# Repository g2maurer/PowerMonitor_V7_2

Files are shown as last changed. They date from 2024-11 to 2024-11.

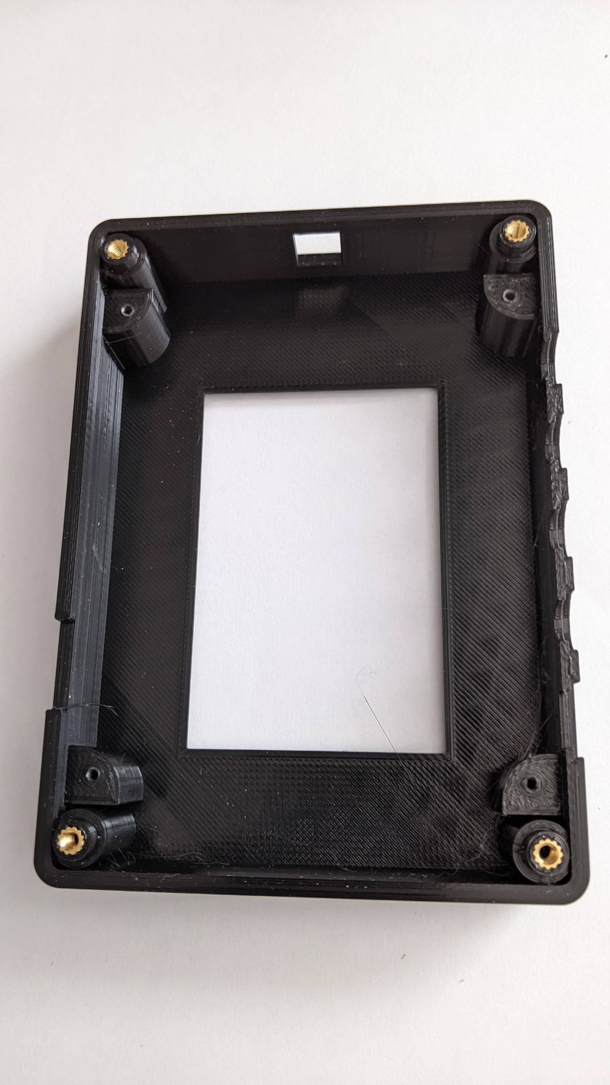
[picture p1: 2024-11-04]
Images/Enclosure_top.jpg

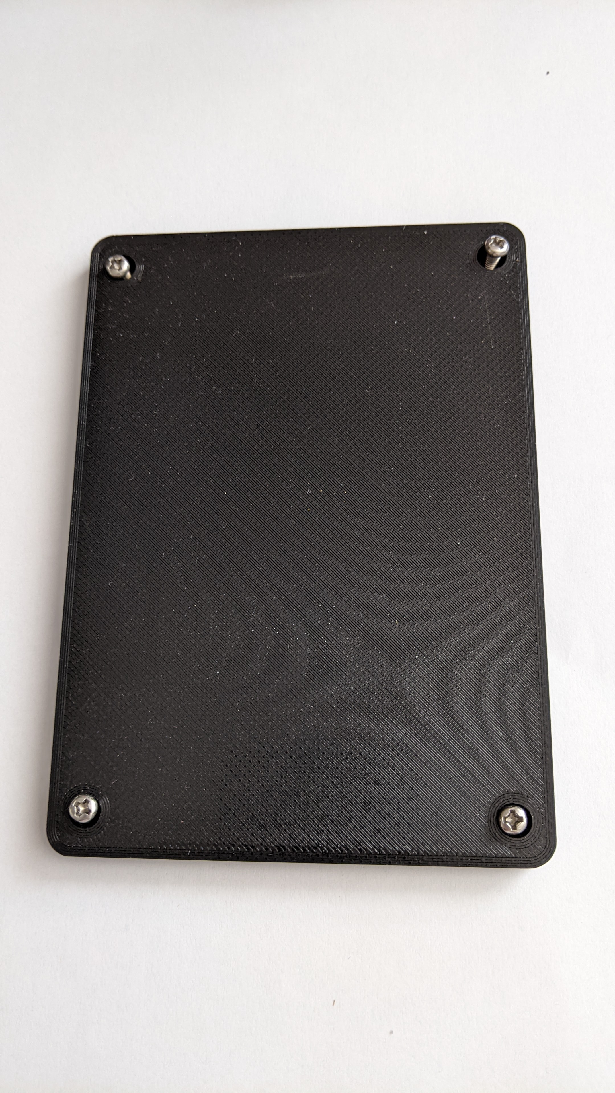
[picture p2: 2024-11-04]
Images/Enclosure back.jpg

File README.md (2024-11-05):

# PowerMonitor_V7_2

## Code:
* ESP32 code files.
* Compile with Arduino Sketch IDE version 1.8.19.
* ESP Board Manager - esp32 by Espressif Systems version 2.0.17.
	* NOTE: Don't try to use newer versions (3.0.x or newer).
* Board: DOIT ESP32 DEVKIT V1

* Required Libraries:
	* RV3028C7.h - Realtime Clock
	* TimeLib.h -
	* Adafruit_ADS1X15.h - Analog-to-Digital converter.
	* WiFi.h
	* WiFiUdp.h
	* NTPClient.h
	* TFT_eSPI.h - TFT screen with Touch.
	* SD.h - SD memory card.
	* SPIFFS.h

## Enclosure:
* STL files for enclosure (front and back).
* FreeCAD enclosure design files.

## Images:
* Image files for PCB and enclosure.

## PCB:
* KiCAD
	* PCB design files.
* PCB Components:
	* ESP32-WROOM-32S.
	* 3.5 inch TFT with Touch. 
		* SPI interface.
	* ADS1015 Analog to Digital converter ICs. 
		* Configured in differntail mode, two CT channels per A2D converter IC.
	* CH340K USB to serial inteface IC.
		* microUSB interface (USB-B).
	* RV3028__C7 Realtime Clock IC and battery. 
		* Not required if WiFi connected to get the time via NTP.

## Misc:
* TFT user setup file. 
	* Contains the ESP32 to TFT pin definitions.
	* The TFT_eSPI "User_Setup_Select.h" file selects the User_Setup file. 
	* Use ILI9488_g2m.h file found in Misc directory for User_Setup file.

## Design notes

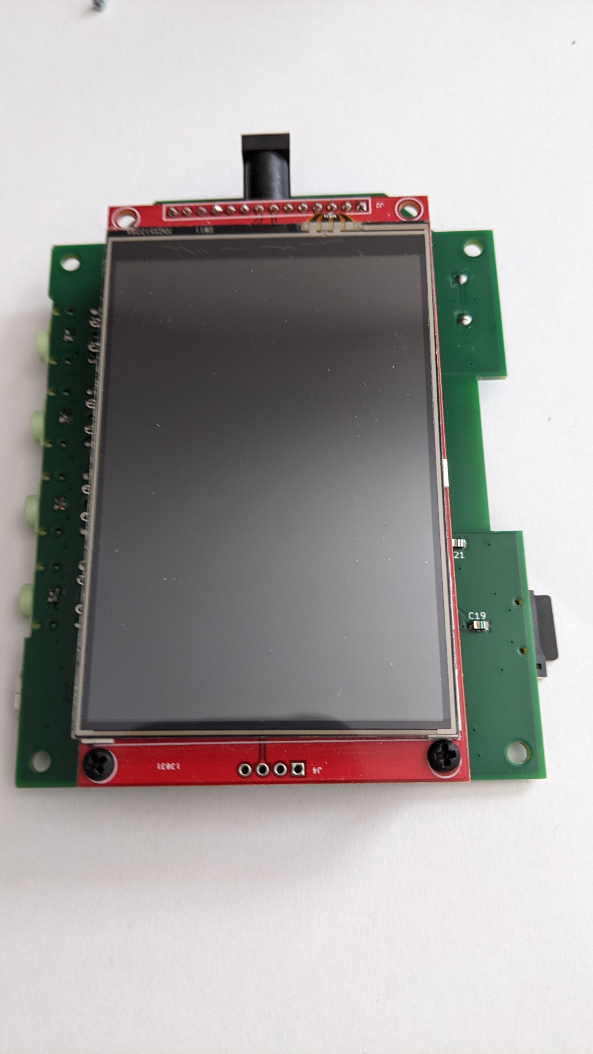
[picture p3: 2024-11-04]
Images/PCB_back_w_TFT.jpg

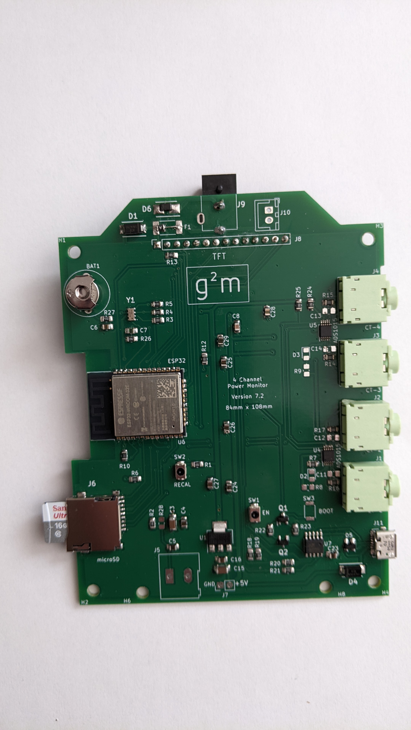
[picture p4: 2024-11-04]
Images/PCB_front.jpg

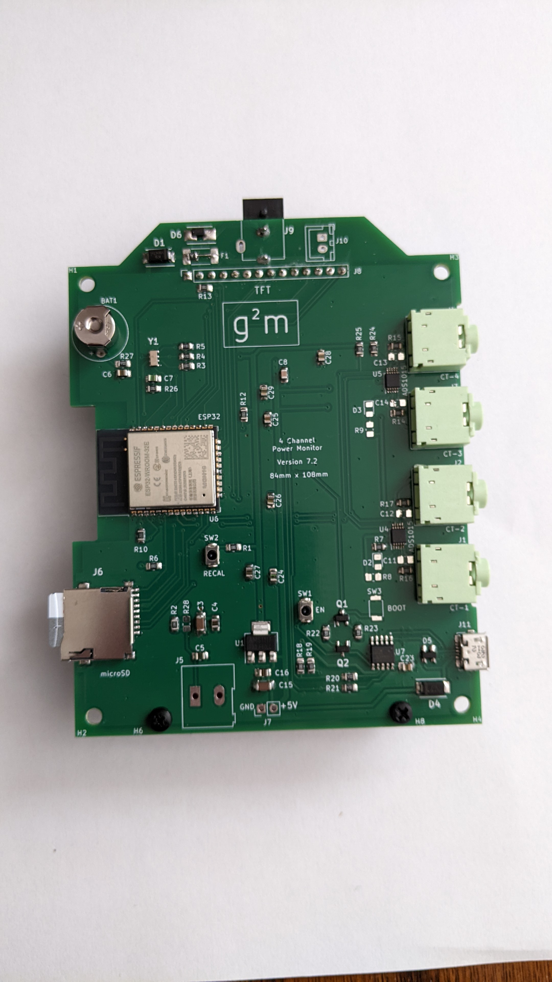
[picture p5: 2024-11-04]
Images/PCB_front_w_TFT.jpg

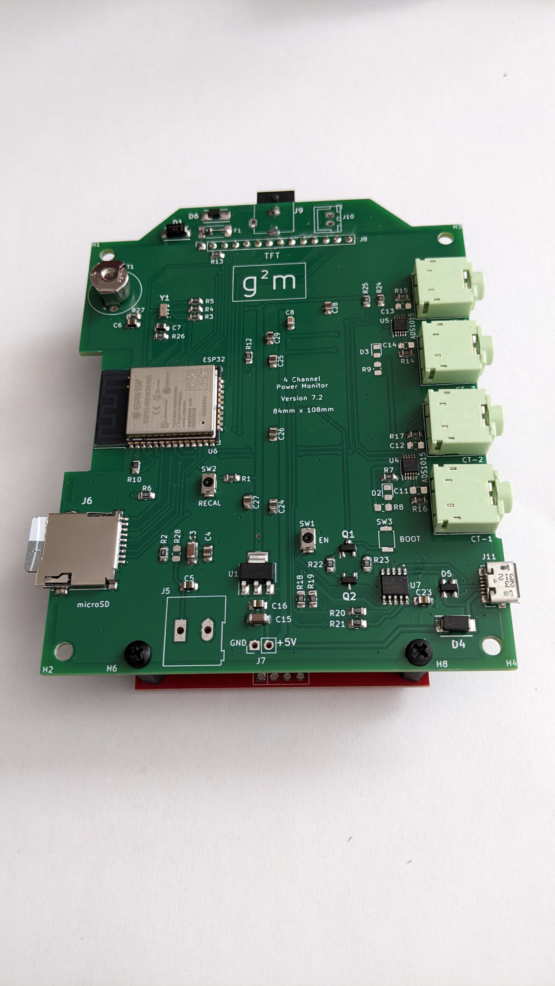
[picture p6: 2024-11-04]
Images/PCB_front_w_TFT_2.jpg

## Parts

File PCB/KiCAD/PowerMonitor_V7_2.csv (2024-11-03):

Source: | C:\Users\gmaur\Documents\KiCad Projects\PowerMonitor_V7_2\PowerMonitor_V7_2.sch
Date: | 8/19/2024 11:29:42 AM
Tool: | Eeschema (5.1.10)-1
Generator: | C:\Program Files\KiCad\bin\scripting\plugins/bom_csv_grouped_by_value.py
Component Count: | 94
Individual Components:
Item | Qty | Reference(s) | Value | LibPart | Footprint | Datasheet | Arrow Part Number | Arrow Price/Stock | Description | Height | Manufacturer_Name | Manufacturer_Part_Number | Mouser Part Number | Mouser Price/Stock
 |  | BAT1 | SR754 | Custom:SR754_Battery | BatteruyHolder:Battery_Retainer_size_13 | ~
 |  | C1 | 100nF | Device:C_Small | Capacitor_SMD:C_0805_2012Metric_Pad1.18x1.45mm_HandSolder | ~
 |  | C2 | 100nF | Device:C_Small | Capacitor_SMD:C_0805_2012Metric_Pad1.18x1.45mm_HandSolder | ~
 |  | C3 | 10uF | Device:CP_Small | Capacitor_SMD:C_1206_3216Metric_Pad1.33x1.80mm_HandSolder | ~
 |  | C4 | 100nF | Device:C_Small | Capacitor_SMD:C_0805_2012Metric_Pad1.18x1.45mm_HandSolder | ~
 |  | C5 | 100nF | Device:C_Small | Capacitor_SMD:C_0805_2012Metric_Pad1.18x1.45mm_HandSolder | ~
 |  | C6 | 100nF | Device:C_Small | Capacitor_SMD:C_0805_2012Metric_Pad1.18x1.45mm_HandSolder | ~
 |  | C7 | 100nF | Device:C_Small | Capacitor_SMD:C_0805_2012Metric_Pad1.18x1.45mm_HandSolder | ~
 |  | C8 | 1uF | Device:C_Small | Capacitor_SMD:C_0805_2012Metric_Pad1.18x1.45mm_HandSolder | ~
 |  | C9 | 10nF | Device:C_Small | Capacitor_SMD:C_0805_2012Metric_Pad1.18x1.45mm_HandSolder | ~
 |  | C10 | 2.2uF | Device:CP_Small | Capacitor_SMD:C_1206_3216Metric_Pad1.33x1.80mm_HandSolder | ~
 |  | C11 | 10nF | Device:C_Small | Capacitor_SMD:C_0805_2012Metric_Pad1.18x1.45mm_HandSolder | ~
 |  | C12 | 10nF | Device:C_Small | Capacitor_SMD:C_0805_2012Metric_Pad1.18x1.45mm_HandSolder | ~
 |  | C13 | 10nF | Device:C_Small | Capacitor_SMD:C_0805_2012Metric_Pad1.18x1.45mm_HandSolder | ~
 |  | C14 | 10nF | Device:C_Small | Capacitor_SMD:C_0805_2012Metric_Pad1.18x1.45mm_HandSolder | ~
 |  | C15 | 10uF | Device:C_Small | Capacitor_SMD:C_1206_3216Metric_Pad1.33x1.80mm_HandSolder | ~
 |  | C16 | 100nF | Device:C_Small | Capacitor_SMD:C_0805_2012Metric_Pad1.18x1.45mm_HandSolder | ~
 |  | C17 | 100nF | Device:C_Small | Capacitor_SMD:C_0805_2012Metric_Pad1.18x1.45mm_HandSolder | ~
 |  | C18 | 10uF | Device:C_Small | Capacitor_SMD:C_1206_3216Metric_Pad1.33x1.80mm_HandSolder | ~
 |  | C19 | 100nF | Device:C_Small | Capacitor_SMD:C_0805_2012Metric_Pad1.18x1.45mm_HandSolder | ~
 |  | C20 | 10nF | Device:C_Small | Capacitor_SMD:C_0805_2012Metric_Pad1.18x1.45mm_HandSolder | ~
 |  | C21 | 100nF | Device:C_Small | Capacitor_SMD:C_0805_2012Metric_Pad1.18x1.45mm_HandSolder | ~
 |  | C22 | 100nF | Device:C_Small | Capacitor_SMD:C_0805_2012Metric_Pad1.18x1.45mm_HandSolder | ~
 |  | C23 | 100nF | Device:C_Small | Capacitor_SMD:C_0805_2012Metric_Pad1.18x1.45mm_HandSolder | ~
 |  | C24 | 100nF | Device:C_Small | Capacitor_SMD:C_0805_2012Metric_Pad1.18x1.45mm_HandSolder | ~
 |  | C25 | 100nF | Device:C_Small | Capacitor_SMD:C_0805_2012Metric_Pad1.18x1.45mm_HandSolder | ~
 |  | C26 | 100nF | Device:C_Small | Capacitor_SMD:C_0805_2012Metric_Pad1.18x1.45mm_HandSolder | ~
 |  | C27 | 100nF | Device:C_Small | Capacitor_SMD:C_0805_2012Metric_Pad1.18x1.45mm_HandSolder | ~
 |  | C28 | 100nF | Device:C_Small | Capacitor_SMD:C_0805_2012Metric_Pad1.18x1.45mm_HandSolder | ~
 |  | C29 | 100nF | Device:C_Small | Capacitor_SMD:C_0805_2012Metric_Pad1.18x1.45mm_HandSolder | ~
 |  | D1 | 1N5819 | Diode:1N5819 | SamacSys_Parts:DIOM5436X295N | http://www.vishay.com/docs/88525/1n5817.pdf
 |  | D2 | LED | Device:LED | LED_SMD:LED_0805_2012Metric_Pad1.15x1.40mm_HandSolder | ~
 |  | D3 | LED | Device:LED | LED_SMD:LED_0805_2012Metric_Pad1.15x1.40mm_HandSolder | ~
 |  | D4 | 5819SMJE3_TR13 | SamacSys:5819SMJE3_TR13 | SamacSys_Parts:DIOM5436X295N | https://www.arrow.com/en/products/5819smje3tr13/microchip-technology | 5819SMJE3/TR13 | null?region=nac | Schottky Diodes & Rectifiers Schottky | 2.95 | Microchip | 5819SMJE3/TR13 | 494-5819SMJE3/TR13 | https://www.mouser.co.uk/ProductDetail/Microchip-Technology/5819SMJE3-TR13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
 |  | D5 | SP0503BAHT | Power_Protection:SP0503BAHT | Package_TO_SOT_SMD:SOT-143 | http://www.littelfuse.com/~/media/files/littelfuse/technical%20resources/documents/data%20sheets/sp05xxba.pdf
 |  | D6 | SMAZ6V2 | Device:D_Zener | DIODE_SMD:DO-214AA | ~
 |  | F1 | Polyfuse_Small | Device:Polyfuse_Small | Fuse:Fuse_2512_6332Metric_Pad1.52x3.35mm_HandSolder | ~
 |  | H1 | MountingHole | Mechanical:MountingHole | MountingHole:MountingHole_3.2mm_M3 | ~
 |  | H2 | MountingHole | Mechanical:MountingHole | MountingHole:MountingHole_3.2mm_M3 | ~
 |  | H3 | MountingHole | Mechanical:MountingHole | MountingHole:MountingHole_3.2mm_M3 | ~
 |  | H4 | MountingHole | Mechanical:MountingHole | MountingHole:MountingHole_3.2mm_M3 | ~
 |  | H6 | TFTHole | Mechanical:MountingHole | MountingHole:MountingHole_3.2mm_M3 | ~
 |  | H8 | TFTHole | Mechanical:MountingHole | MountingHole:MountingHole_3.2mm_M3 | ~
 |  | J1 | CT-1 | PowerMonitor_V4-rescue:PJ307_AudioJack_3.5mm-Custom-PowerMonitor_V3-rescue | Connector_Custom:Jack_3.5mm_PJ307_Horizontal | ~
 |  | J2 | CT-2 | PowerMonitor_V4-rescue:PJ307_AudioJack_3.5mm-Custom-PowerMonitor_V3-rescue | Connector_Custom:Jack_3.5mm_PJ307_Horizontal | ~
 |  | J3 | CT-3 | PowerMonitor_V4-rescue:PJ307_AudioJack_3.5mm-Custom-PowerMonitor_V3-rescue | Connector_Custom:Jack_3.5mm_PJ307_Horizontal | ~
 |  | J4 | CT-4 | PowerMonitor_V4-rescue:PJ307_AudioJack_3.5mm-Custom-PowerMonitor_V3-rescue | Connector_Custom:Jack_3.5mm_PJ307_Horizontal | ~
 |  | J5 | Thermister | Connector:Screw_Terminal_01x02 | TerminalBlock:TerminalBlock_Altech_AK300-2_P5.00mm | ~
 |  | J6 | MSD-4-A | SamacSys:MSD-4-A | SamacSys_Parts:MSD4A | https://www.cuidevices.com/product/resource/pdf/msd-4-a.pdf |  |  | Memory Card Connectors 9 Positions, Push In, Auto Eject Out, SMT, 1.8 mm Height Above Board, | 2 | CUI Devices | MSD-4-A | 179-MSD-4-A | https://www.mouser.co.uk/ProductDetail/CUI-Devices/MSD-4-A?qs=Z%252BL2brAPG1Jll%252BQTi%252Btupg%3D%3D
 |  | J7 | Test_5V | Connector_Generic:Conn_01x02 | Connector_PinHeader_2.54mm:PinHeader_1x02_P2.54mm_Vertical | ~
 |  | J8 | TFT | Connector_Generic:Conn_01x14 | Connector_PinSocket_2.54mm:PinSocket_1x14_P2.54mm_Vertical | ~
 |  | J9 | Barrel_Jack_Switch | Connector:Barrel_Jack_Switch | Connector_Custom:PJ-059A | ~
 |  | J10 | +5V IN | Connector_Generic:Conn_01x02 | Connector_JST:JST_XH_B2B-XH-A_1x02_P2.50mm_Vertical | ~
 |  | J11 | USB_B_Micro | Connector:USB_B_Micro | Connector_USB:USB_Micro-B_Molex_47346-0001 | ~
 |  | Q1 | MMSS8050-H-TP | SamacSys:MMSS8050-H-TP | SamacSys_Parts:SOT95P237X125-3N | https://www.mccsemi.com/pdf/Products/MMSS8050(SOT-23).pdf | MMSS8050-H-TP | https://www.arrow.com/en/products/mmss8050-h-tp/micro-commercial-components?region=europe | Small Signal Bipolar Transistors | 1.25 | MCC | MMSS8050-H-TP | 833-MMSS8050-H-TP | https://www.mouser.co.uk/ProductDetail/Micro-Commercial-Components-MCC/MMSS8050-H-TP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
 |  | Q2 | MMSS8050-H-TP | SamacSys:MMSS8050-H-TP | SamacSys_Parts:SOT95P237X125-3N | https://www.mccsemi.com/pdf/Products/MMSS8050(SOT-23).pdf | MMSS8050-H-TP | https://www.arrow.com/en/products/mmss8050-h-tp/micro-commercial-components?region=europe | Small Signal Bipolar Transistors | 1.25 | MCC | MMSS8050-H-TP | 833-MMSS8050-H-TP | https://www.mouser.co.uk/ProductDetail/Micro-Commercial-Components-MCC/MMSS8050-H-TP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
 |  | R1 | 10k | Device:R_Small_US | Resistor_SMD:R_0805_2012Metric_Pad1.20x1.40mm_HandSolder | ~
 |  | R2 | 1k | Device:R_Small_US | Resistor_SMD:R_0805_2012Metric_Pad1.20x1.40mm_HandSolder | ~
 |  | R3 | 10k | Device:R_Small_US | Resistor_SMD:R_0805_2012Metric_Pad1.20x1.40mm_HandSolder | ~
 |  | R4 | 4.7k | Device:R_Small_US | Resistor_SMD:R_0805_2012Metric_Pad1.20x1.40mm_HandSolder | ~
 |  | R5 | 4.7k | Device:R_Small_US | Resistor_SMD:R_0805_2012Metric_Pad1.20x1.40mm_HandSolder | ~
 |  | R6 | 10k | Device:R_Small_US | Resistor_SMD:R_0805_2012Metric_Pad1.20x1.40mm_HandSolder | ~
 |  | R7 | 10k | Device:R_Small_US | Resistor_SMD:R_0805_2012Metric_Pad1.20x1.40mm_HandSolder | ~
 |  | R8 | 10k | Device:R_Small_US | Resistor_SMD:R_0805_2012Metric_Pad1.20x1.40mm_HandSolder | ~
 |  | R9 | 10k | Device:R_Small_US | Resistor_SMD:R_0805_2012Metric_Pad1.20x1.40mm_HandSolder | ~
 |  | R10 | 12k | Device:R_Small_US | Resistor_SMD:R_0805_2012Metric_Pad1.20x1.40mm_HandSolder | ~
 |  | R11 | 10k | Device:R_Small_US | Resistor_SMD:R_0805_2012Metric_Pad1.20x1.40mm_HandSolder | ~
 |  | R12 | 10k | Device:R_Small_US | Resistor_SMD:R_0805_2012Metric_Pad1.20x1.40mm_HandSolder | ~
 |  | R13 | 10k | Device:R_Small_US | Resistor_SMD:R_0805_2012Metric_Pad1.20x1.40mm_HandSolder | ~
 |  | R14 | 10k | Device:R_Small_US | Resistor_SMD:R_0805_2012Metric_Pad1.20x1.40mm_HandSolder | ~
 |  | R15 | 10k | Device:R_Small_US | Resistor_SMD:R_0805_2012Metric_Pad1.20x1.40mm_HandSolder | ~
 |  | R16 | 10k | Device:R_Small_US | Resistor_SMD:R_0805_2012Metric_Pad1.20x1.40mm_HandSolder | ~
 |  | R17 | 10k | Device:R_Small_US | Resistor_SMD:R_0805_2012Metric_Pad1.20x1.40mm_HandSolder | ~
 |  | R18 | 10k | Device:R_Small_US | Resistor_SMD:R_0805_2012Metric_Pad1.20x1.40mm_HandSolder | ~
 |  | R19 | 10k | Device:R_Small_US | Resistor_SMD:R_0805_2012Metric_Pad1.20x1.40mm_HandSolder | ~
 |  | R20 | 470 | Device:R_Small_US | Resistor_SMD:R_0805_2012Metric_Pad1.20x1.40mm_HandSolder | ~
 |  | R21 | 470 | Device:R_Small_US | Resistor_SMD:R_0805_2012Metric_Pad1.20x1.40mm_HandSolder | ~
 |  | R22 | 5.1k | Device:R_Small_US | Resistor_SMD:R_0805_2012Metric_Pad1.20x1.40mm_HandSolder | ~
 |  | R23 | 5.1k | Device:R_Small_US | Resistor_SMD:R_0805_2012Metric_Pad1.20x1.40mm_HandSolder | ~
 |  | R24 | 10k | Device:R_Small_US | Resistor_SMD:R_0805_2012Metric_Pad1.20x1.40mm_HandSolder | ~
 |  | R25 | 10k | Device:R_Small_US | Resistor_SMD:R_0805_2012Metric_Pad1.20x1.40mm_HandSolder | ~
 |  | R26 | 10k | Device:R_Small_US | Resistor_SMD:R_0805_2012Metric_Pad1.20x1.40mm_HandSolder | ~
 |  | R27 | 470 | Device:R_Small_US | Resistor_SMD:R_0805_2012Metric_Pad1.20x1.40mm_HandSolder | ~
 |  | R28 | 1.5k | Device:R_Small_US | Resistor_SMD:R_0805_2012Metric_Pad1.20x1.40mm_HandSolder | ~
 |  | SW1 | EN | Switch:SW_Push | CustomFootprints:SW_SPST_ALPS_SKRKA | ~
 |  | SW2 | Recal Touch | Switch:SW_Push | CustomFootprints:SW_SPST_ALPS_SKRKA | ~
 |  | SW3 | Boot | Switch:SW_Push | CustomFootprints:SW_SPST_ALPS_SKRKA | ~
 |  | U1 | AMS1117-3.3 | Regulator_Linear:AMS1117-3.3 | Package_TO_SOT_SMD:SOT-223-3_TabPin2 | http://www.advanced-monolithic.com/pdf/ds1117.pdf
 |  | U3 | LP2985-3.3 | Regulator_Linear:LP2985-3.3 | Package_TO_SOT_SMD:SOT-23-5 | http://www.ti.com/lit/ds/symlink/lp2985.pdf
 |  | U4 | ADS1015IDGS | Analog_ADC:ADS1015IDGS | Package_SO:TSSOP-10_3x3mm_P0.5mm | http://www.ti.com/lit/ds/symlink/ads1015.pdf
 |  | U5 | ADS1015IDGS | Analog_ADC:ADS1015IDGS | Package_SO:TSSOP-10_3x3mm_P0.5mm | http://www.ti.com/lit/ds/symlink/ads1015.pdf
 |  | U6 | ESP32-WROOM | ESP32-footprints-Shem-Lib:ESP32-WROOM | RF_Module:ESP32-WROOM-32
 |  | U7 | CH340K | CH340K:CH340K | CH340K:SOP100P600X160-11N
 |  | Y1 | RV-3028-C7_32.768KHZ_1PPM-TA-QA | SamacSys:RV-3028-C7_32.768KHZ_1PPM-TA-QA | SamacSys_Parts:RV3028C732768KHZ1PPMTAQA | https://www.microcrystal.com/fileadmin/Media/Products/RTC/Datasheet/RV-3028-C7.pdf |  |  | IC RTC CLK/CALENDAR I2C 8SON | 0.8 | Micro Crystal AG | RV-3028-C7 32.768KHZ 1PPM-TA-QA
Collated Components:
Item | Qty | Reference(s) | Value | LibPart | Footprint | Datasheet | Arrow Part Number | Arrow Price/Stock | Description | Height | Manufacturer_Name | Manufacturer_Part_Number | Mouser Part Number | Mouser Price/Stock
1 | 1 | BAT1 | SR754 | Custom:SR754_Battery | BatteruyHolder:Battery_Retainer_size_13 | ~
2 | 18 | C1, C2, C4, C5, C6, C7, C16, C17, C19, C21, C22, C23, C24, C25, C26, C27, C28, C29 | 100nF | Device:C_Small | Capacitor_SMD:C_0805_2012Metric_Pad1.18x1.45mm_HandSolder | ~
3 | 1 | C3 | 10uF | Device:CP_Small | Capacitor_SMD:C_1206_3216Metric_Pad1.33x1.80mm_HandSolder | ~
4 | 1 | C8 | 1uF | Device:C_Small | Capacitor_SMD:C_0805_2012Metric_Pad1.18x1.45mm_HandSolder | ~
5 | 6 | C9, C11, C12, C13, C14, C20 | 10nF | Device:C_Small | Capacitor_SMD:C_0805_2012Metric_Pad1.18x1.45mm_HandSolder | ~
6 | 1 | C10 | 2.2uF | Device:CP_Small | Capacitor_SMD:C_1206_3216Metric_Pad1.33x1.80mm_HandSolder | ~
7 | 2 | C15, C18 | 10uF | Device:C_Small | Capacitor_SMD:C_1206_3216Metric_Pad1.33x1.80mm_HandSolder | ~
8 | 1 | D1 | 1N5819 | Diode:1N5819 | SamacSys_Parts:DIOM5436X295N | http://www.vishay.com/docs/88525/1n5817.pdf
9 | 2 | D2, D3 | LED | Device:LED | LED_SMD:LED_0805_2012Metric_Pad1.15x1.40mm_HandSolder | ~
10 | 1 | D4 | 5819SMJE3_TR13 | SamacSys:5819SMJE3_TR13 | SamacSys_Parts:DIOM5436X295N | https://www.arrow.com/en/products/5819smje3tr13/microchip-technology | 5819SMJE3/TR13 | null?region=nac | Schottky Diodes & Rectifiers Schottky | 2.95 | Microchip | 5819SMJE3/TR13 | 494-5819SMJE3/TR13 | https://www.mouser.co.uk/ProductDetail/Microchip-Technology/5819SMJE3-TR13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
11 | 1 | D5 | SP0503BAHT | Power_Protection:SP0503BAHT | Package_TO_SOT_SMD:SOT-143 | http://www.littelfuse.com/~/media/files/littelfuse/technical%20resources/documents/data%20sheets/sp05xxba.pdf
12 | 1 | D6 | SMAZ6V2 | Device:D_Zener | DIODE_SMD:DO-214AA | ~
13 | 1 | F1 | Polyfuse_Small | Device:Polyfuse_Small | Fuse:Fuse_2512_6332Metric_Pad1.52x3.35mm_HandSolder | ~
14 | 4 | H1, H2, H3, H4 | MountingHole | Mechanical:MountingHole | MountingHole:MountingHole_3.2mm_M3 | ~
15 | 2 | H6, H8 | TFTHole | Mechanical:MountingHole | MountingHole:MountingHole_3.2mm_M3 | ~
16 | 1 | J1 | CT-1 | PowerMonitor_V4-rescue:PJ307_AudioJack_3.5mm-Custom-PowerMonitor_V3-rescue | Connector_Custom:Jack_3.5mm_PJ307_Horizontal | ~
17 | 1 | J2 | CT-2 | PowerMonitor_V4-rescue:PJ307_AudioJack_3.5mm-Custom-PowerMonitor_V3-rescue | Connector_Custom:Jack_3.5mm_PJ307_Horizontal | ~
18 | 1 | J3 | CT-3 | PowerMonitor_V4-rescue:PJ307_AudioJack_3.5mm-Custom-PowerMonitor_V3-rescue | Connector_Custom:Jack_3.5mm_PJ307_Horizontal | ~
19 | 1 | J4 | CT-4 | PowerMonitor_V4-rescue:PJ307_AudioJack_3.5mm-Custom-PowerMonitor_V3-rescue | Connector_Custom:Jack_3.5mm_PJ307_Horizontal | ~
20 | 1 | J5 | Thermister | Connector:Screw_Terminal_01x02 | TerminalBlock:TerminalBlock_Altech_AK300-2_P5.00mm | ~
21 | 1 | J6 | MSD-4-A | SamacSys:MSD-4-A | SamacSys_Parts:MSD4A | https://www.cuidevices.com/product/resource/pdf/msd-4-a.pdf |  |  | Memory Card Connectors 9 Positions, Push In, Auto Eject Out, SMT, 1.8 mm Height Above Board, | 2 | CUI Devices | MSD-4-A | 179-MSD-4-A | https://www.mouser.co.uk/ProductDetail/CUI-Devices/MSD-4-A?qs=Z%252BL2brAPG1Jll%252BQTi%252Btupg%3D%3D
22 | 1 | J7 | Test_5V | Connector_Generic:Conn_01x02 | Connector_PinHeader_2.54mm:PinHeader_1x02_P2.54mm_Vertical | ~
23 | 1 | J8 | TFT | Connector_Generic:Conn_01x14 | Connector_PinSocket_2.54mm:PinSocket_1x14_P2.54mm_Vertical | ~
24 | 1 | J9 | Barrel_Jack_Switch | Connector:Barrel_Jack_Switch | Connector_Custom:PJ-059A | ~
25 | 1 | J10 | +5V IN | Connector_Generic:Conn_01x02 | Connector_JST:JST_XH_B2B-XH-A_1x02_P2.50mm_Vertical | ~
26 | 1 | J11 | USB_B_Micro | Connector:USB_B_Micro | Connector_USB:USB_Micro-B_Molex_47346-0001 | ~
27 | 2 | Q1, Q2 | MMSS8050-H-TP | SamacSys:MMSS8050-H-TP | SamacSys_Parts:SOT95P237X125-3N | https://www.mccsemi.com/pdf/Products/MMSS8050(SOT-23).pdf | MMSS8050-H-TP | https://www.arrow.com/en/products/mmss8050-h-tp/micro-commercial-components?region=europe | Small Signal Bipolar Transistors | 1.25 | MCC | MMSS8050-H-TP | 833-MMSS8050-H-TP | https://www.mouser.co.uk/ProductDetail/Micro-Commercial-Components-MCC/MMSS8050-H-TP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
28 | 18 | R1, R3, R6, R7, R8, R9, R11, R12, R13, R14, R15, R16, R17, R18, R19, R24, R25, R26 | 10k | Device:R_Small_US | Resistor_SMD:R_0805_2012Metric_Pad1.20x1.40mm_HandSolder | ~
29 | 1 | R2 | 1k | Device:R_Small_US | Resistor_SMD:R_0805_2012Metric_Pad1.20x1.40mm_HandSolder | ~
30 | 2 | R4, R5 | 4.7k | Device:R_Small_US | Resistor_SMD:R_0805_2012Metric_Pad1.20x1.40mm_HandSolder | ~
31 | 1 | R10 | 12k | Device:R_Small_US | Resistor_SMD:R_0805_2012Metric_Pad1.20x1.40mm_HandSolder | ~
32 | 3 | R20, R21, R27 | 470 | Device:R_Small_US | Resistor_SMD:R_0805_2012Metric_Pad1.20x1.40mm_HandSolder | ~
33 | 2 | R22, R23 | 5.1k | Device:R_Small_US | Resistor_SMD:R_0805_2012Metric_Pad1.20x1.40mm_HandSolder | ~
34 | 1 | R28 | 1.5k | Device:R_Small_US | Resistor_SMD:R_0805_2012Metric_Pad1.20x1.40mm_HandSolder | ~
35 | 1 | SW1 | EN | Switch:SW_Push | CustomFootprints:SW_SPST_ALPS_SKRKA | ~
36 | 1 | SW2 | Recal Touch | Switch:SW_Push | CustomFootprints:SW_SPST_ALPS_SKRKA | ~
37 | 1 | SW3 | Boot | Switch:SW_Push | CustomFootprints:SW_SPST_ALPS_SKRKA | ~
38 | 1 | U1 | AMS1117-3.3 | Regulator_Linear:AMS1117-3.3 | Package_TO_SOT_SMD:SOT-223-3_TabPin2 | http://www.advanced-monolithic.com/pdf/ds1117.pdf
39 | 1 | U3 | LP2985-3.3 | Regulator_Linear:LP2985-3.3 | Package_TO_SOT_SMD:SOT-23-5 | http://www.ti.com/lit/ds/symlink/lp2985.pdf
40 | 2 | U4, U5 | ADS1015IDGS | Analog_ADC:ADS1015IDGS | Package_SO:TSSOP-10_3x3mm_P0.5mm | http://www.ti.com/lit/ds/symlink/ads1015.pdf
41 | 1 | U6 | ESP32-WROOM | ESP32-footprints-Shem-Lib:ESP32-WROOM | RF_Module:ESP32-WROOM-32
42 | 1 | U7 | CH340K | CH340K:CH340K | CH340K:SOP100P600X160-11N
43 | 1 | Y1 | RV-3028-C7_32.768KHZ_1PPM-TA-QA | SamacSys:RV-3028-C7_32.768KHZ_1PPM-TA-QA | SamacSys_Parts:RV3028C732768KHZ1PPMTAQA | https://www.microcrystal.com/fileadmin/Media/Products/RTC/Datasheet/RV-3028-C7.pdf |  |  | IC RTC CLK/CALENDAR I2C 8SON | 0.8 | Micro Crystal AG | RV-3028-C7 32.768KHZ 1PPM-TA-QA

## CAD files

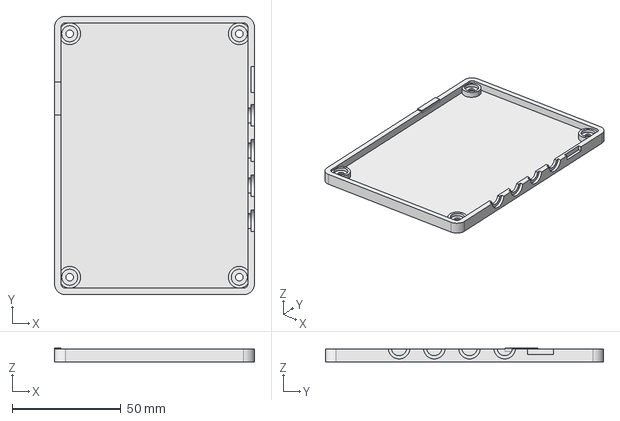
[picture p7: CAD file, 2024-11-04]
Enclosure/FreeCAD/AmpMtrXSmallBack_V4.FCStd
92.0 x 128.0 x 6.60 mm

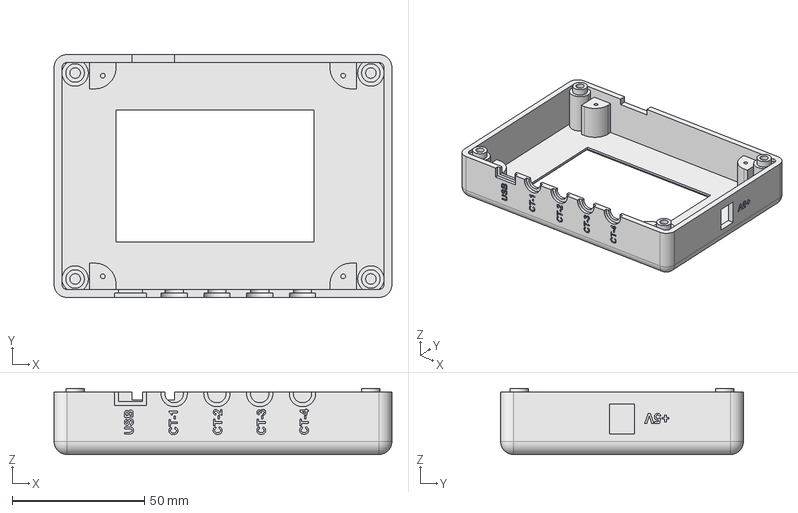
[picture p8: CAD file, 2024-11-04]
Enclosure/FreeCAD/NewAmpMeter_V4_Cpy11.FCStd
128.0 x 92.0 x 25.0 mm

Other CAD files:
Enclosure/AmpMtrXSmallBack_V4.stl
Enclosure/NewAmpMeter_V4_Cpy11.stl

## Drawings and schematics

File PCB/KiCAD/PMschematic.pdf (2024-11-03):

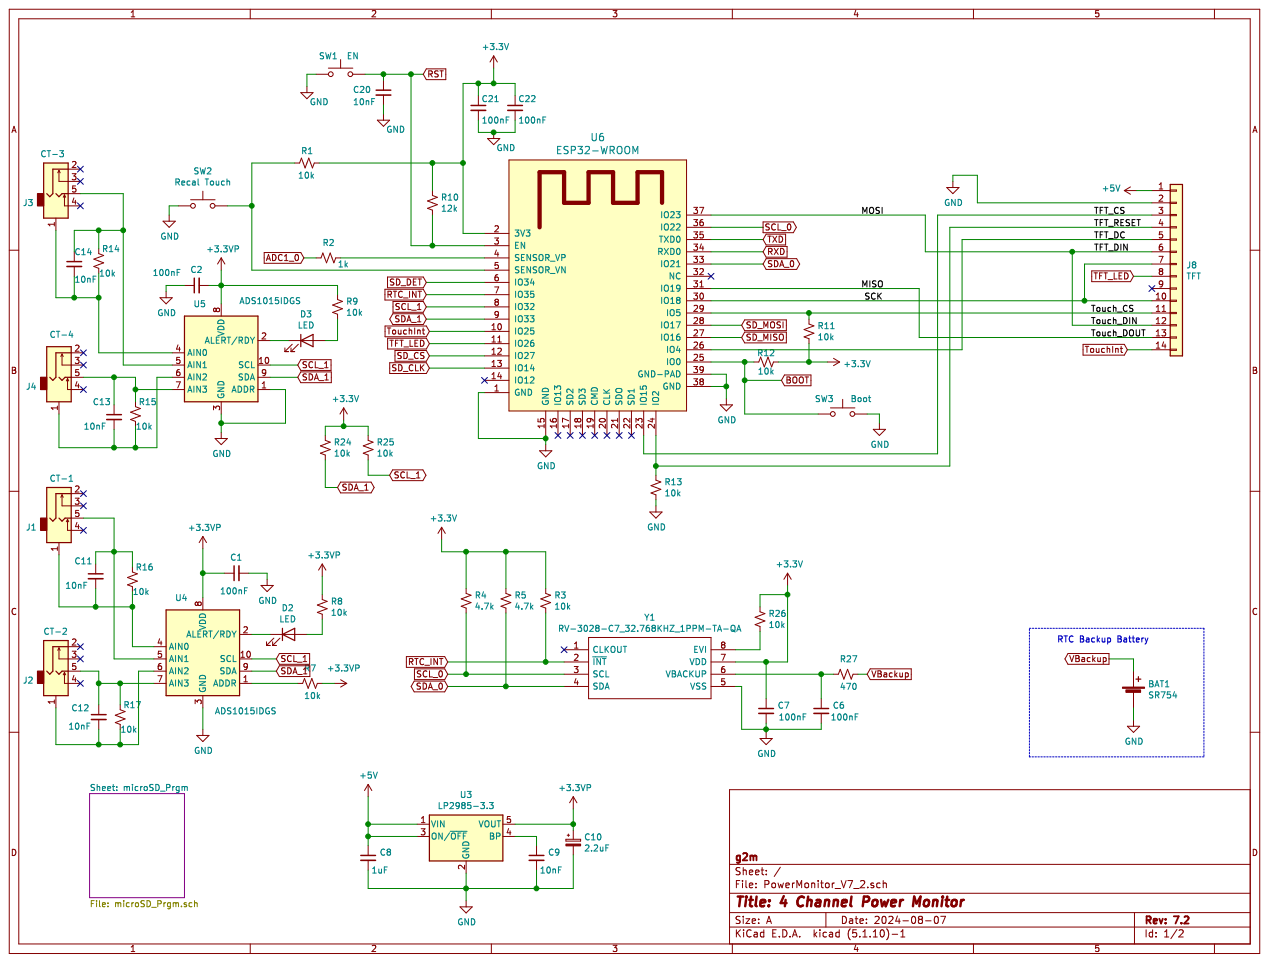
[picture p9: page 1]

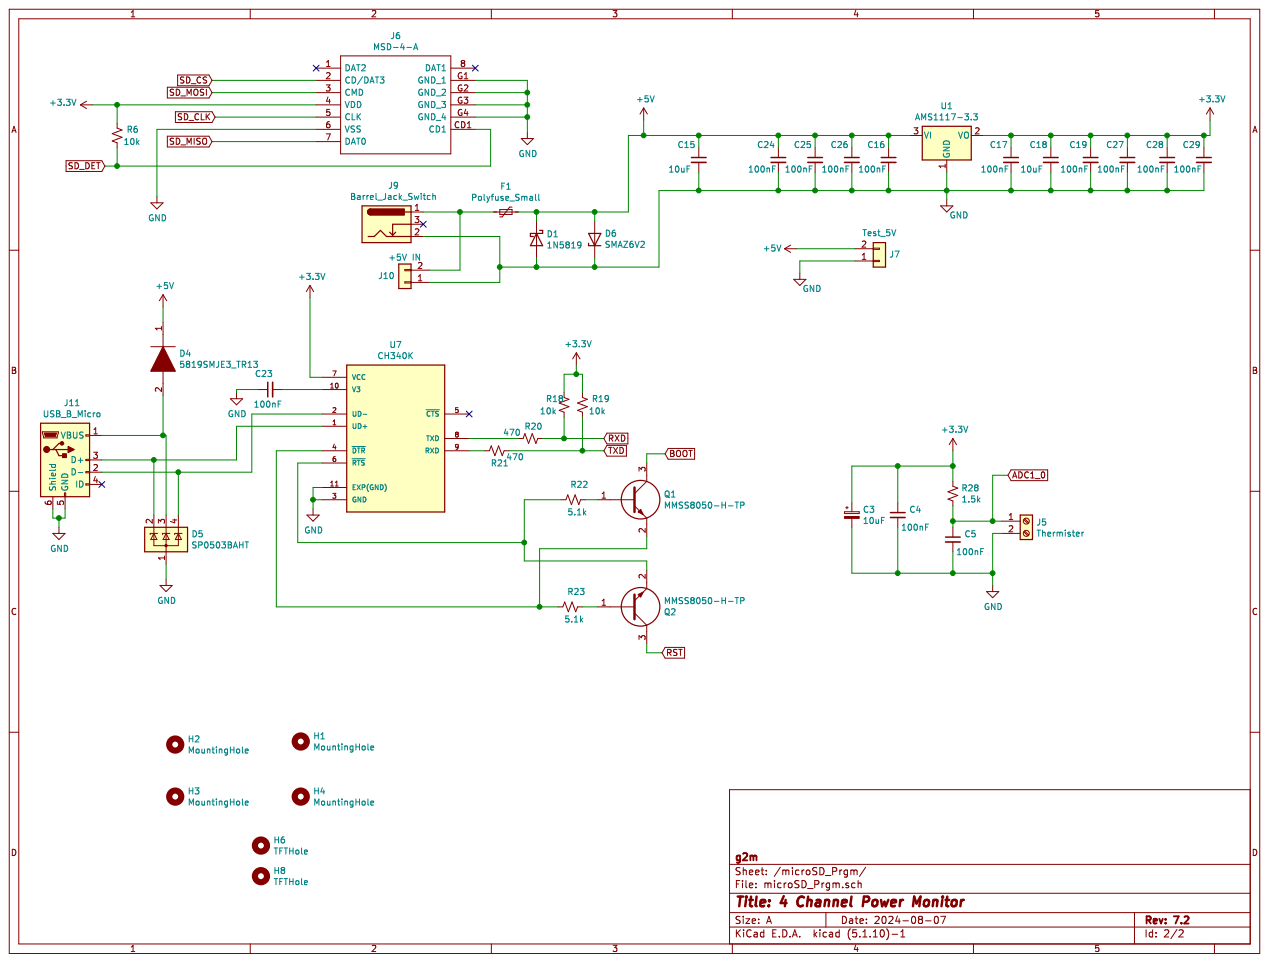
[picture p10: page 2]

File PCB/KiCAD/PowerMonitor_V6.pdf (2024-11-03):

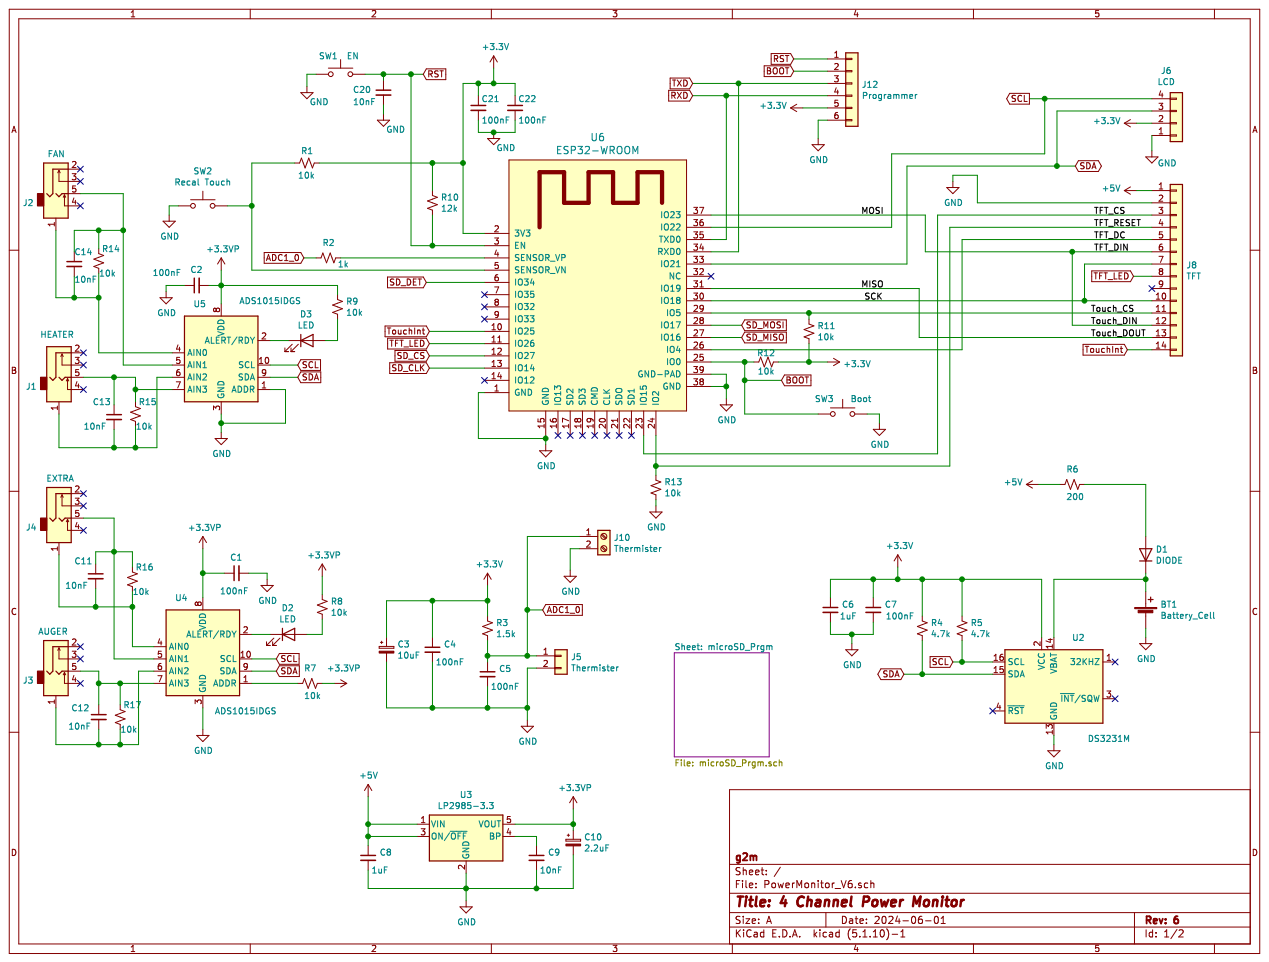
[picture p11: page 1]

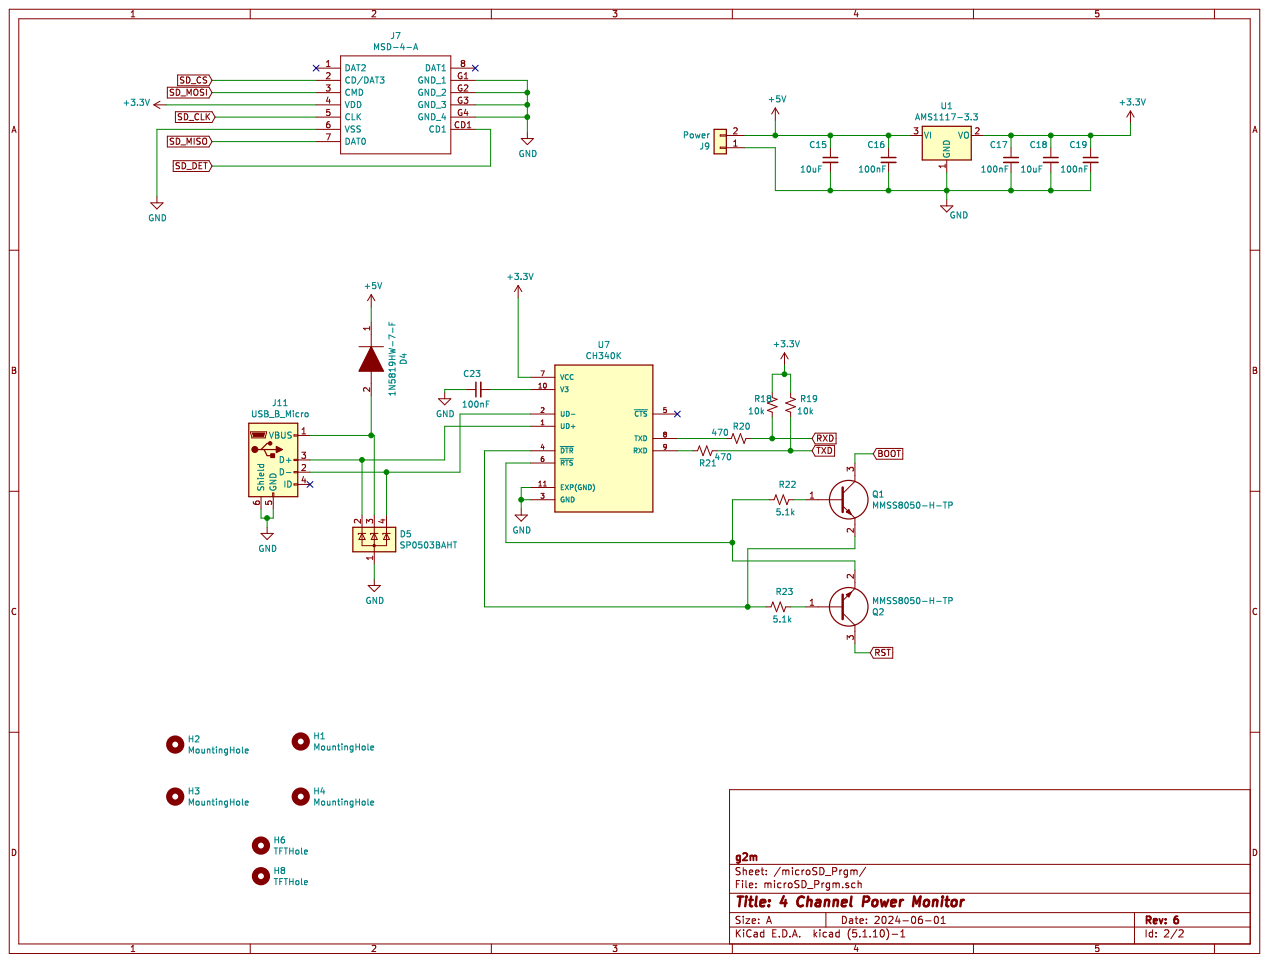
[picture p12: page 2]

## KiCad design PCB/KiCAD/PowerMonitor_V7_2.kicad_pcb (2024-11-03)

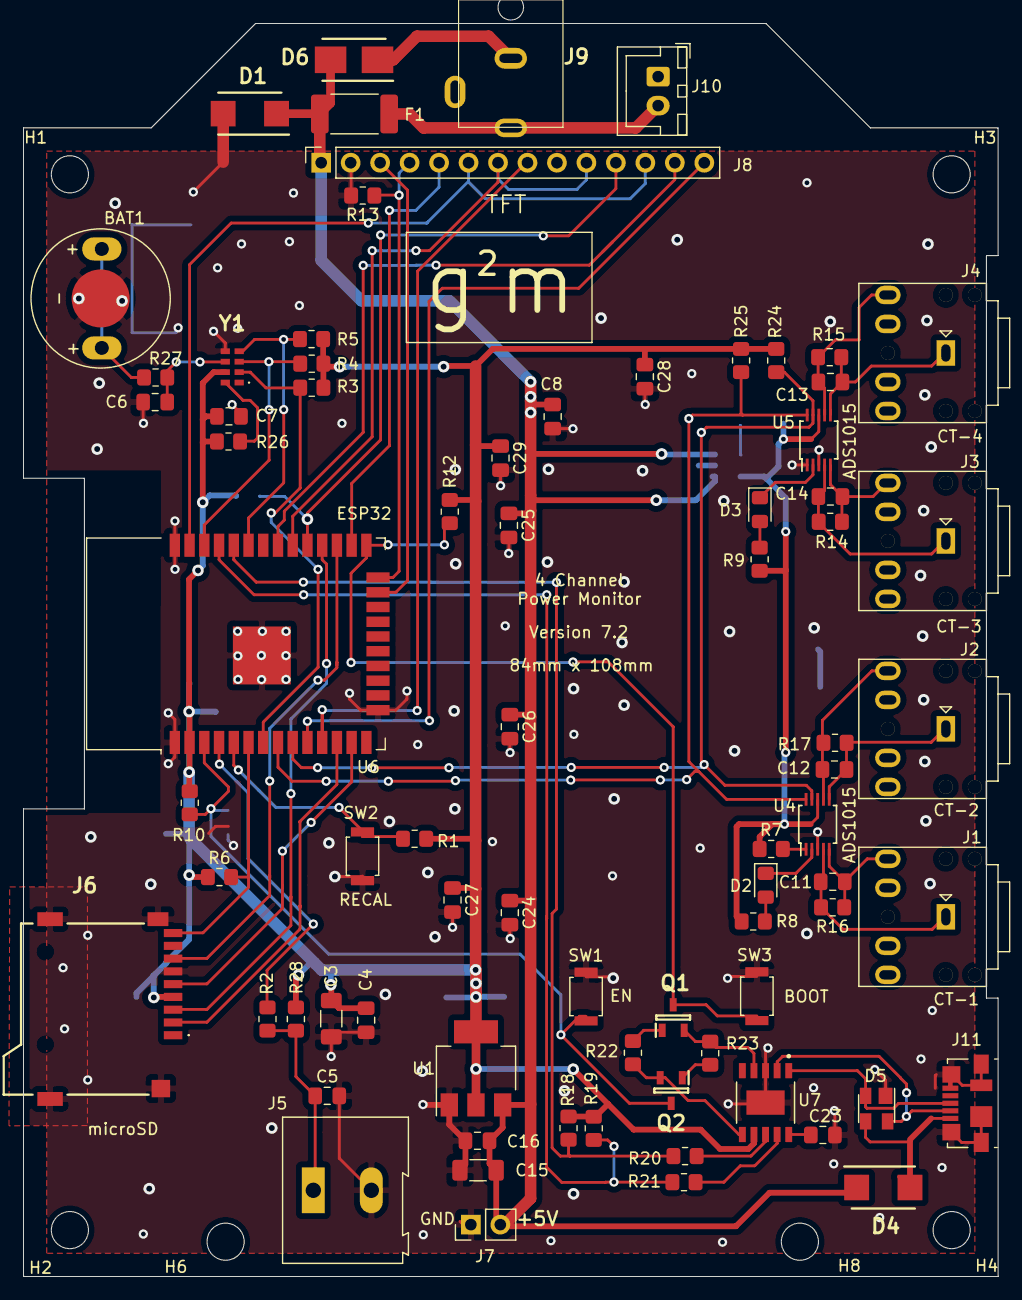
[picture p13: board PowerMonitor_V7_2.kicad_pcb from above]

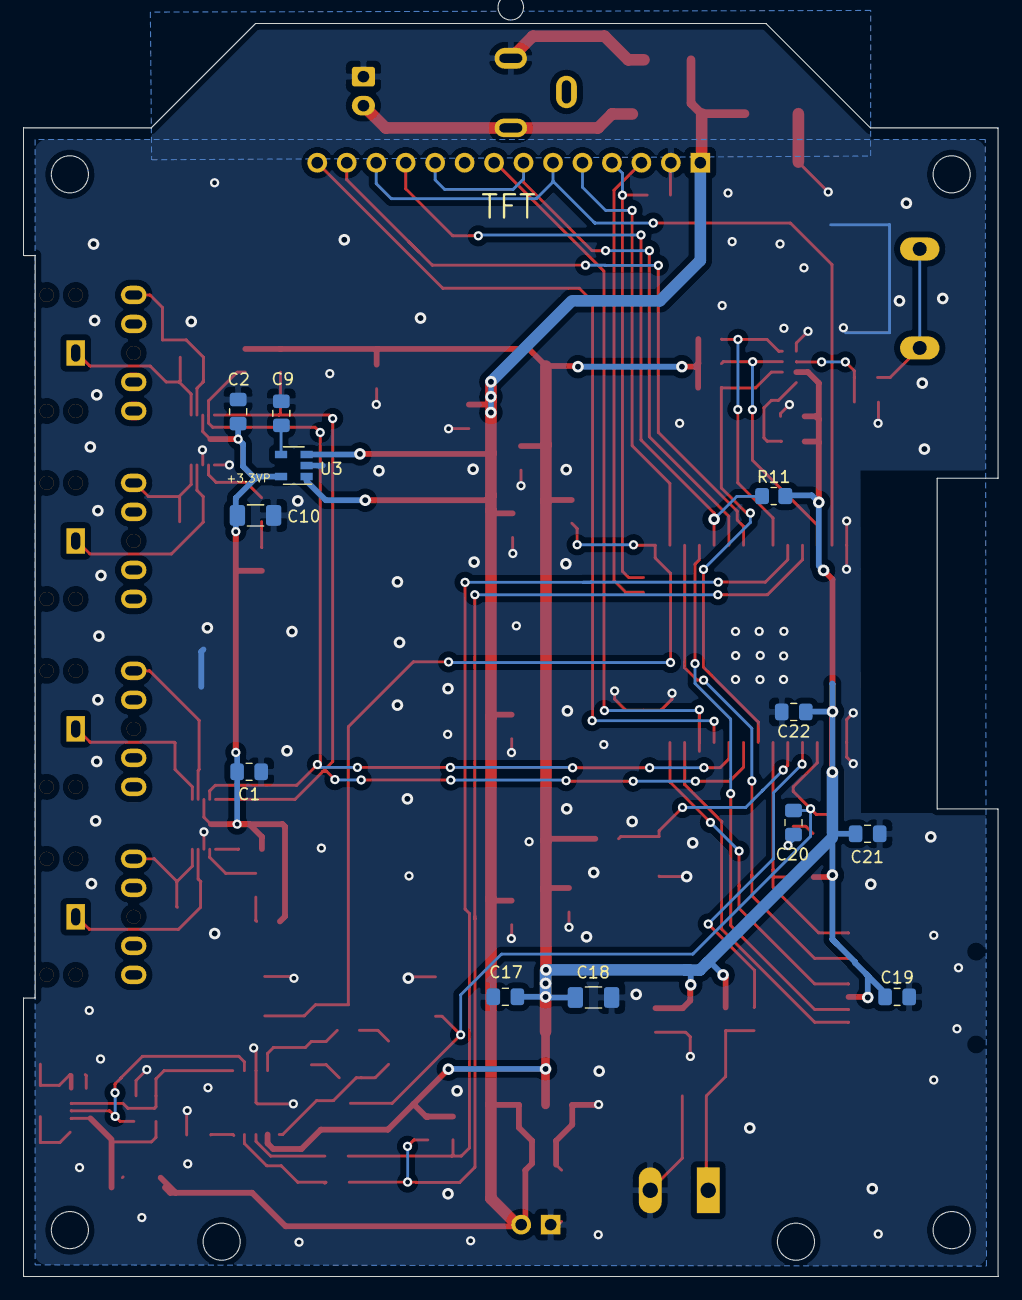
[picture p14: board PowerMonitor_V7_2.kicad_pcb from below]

Board: 2 copper layers, 84.0 x 108.0 mm, 94 parts (12 on the bottom side), 58 nets.

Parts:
BAT1: SR754; Battery_Retainer_size_13
C1, C2, C4, C5, C6, C7, C16, C17, C19, C21, C22, C23, C24, C25, C26, C27, C28, C29: 100nF; C_0805_2012Metric_Pad1.18x1.45mm_HandSolder
C3, C15, C18: 10uF; C_1206_3216Metric_Pad1.33x1.80mm_HandSolder
C8: 1uF; C_0805_2012Metric_Pad1.18x1.45mm_HandSolder
C9, C11, C12, C13, C14, C20: 10nF; C_0805_2012Metric_Pad1.18x1.45mm_HandSolder
C10: 2.2uF; C_1206_3216Metric_Pad1.33x1.80mm_HandSolder
D1: 1N5819; DIOM5436X295N
D2, D3: LED; LED_0805_2012Metric_Pad1.15x1.40mm_HandSolder
D4: 5819SMJE3_TR13; DIOM5436X295N
D5: SP0503BAHT; SOT-143
D6: SMAZ6V2; DO-214AA
F1: Polyfuse_Small; Fuse_2512_6332Metric_Pad1.52x3.35mm_HandSolder
H1, H2, H3, H4: MountingHole; MountingHole_3.2mm_M3
H6, H8: TFTHole; MountingHole_3.2mm_M3
J1: CT-1; Jack_3.5mm_PJ307_Horizontal
J2: CT-2; Jack_3.5mm_PJ307_Horizontal
J3: CT-3; Jack_3.5mm_PJ307_Horizontal
J4: CT-4; Jack_3.5mm_PJ307_Horizontal
J5: Thermister; TerminalBlock_Altech_AK300-2_P5.00mm
J6: MSD-4-A; MSD4A
J7: Test_5V; PinHeader_1x02_P2.54mm_Vertical
J8: TFT; PinSocket_1x14_P2.54mm_Vertical
J9: Barrel_Jack_Switch; PJ-059A
J10: +5V IN; JST_XH_B2B-XH-A_1x02_P2.50mm_Vertical
J11: USB_B_Micro; USB_Micro-B_Molex_47346-0001
Q1, Q2: MMSS8050-H-TP; SOT95P237X125-3N
R1, R3, R6, R7, R8, R9, R11, R12, R13, R14, R15, R16, R17, R18, R19, R24, R25, R26: 10k; R_0805_2012Metric_Pad1.20x1.40mm_HandSolder
R2: 1k; R_0805_2012Metric_Pad1.20x1.40mm_HandSolder
R4, R5: 4.7k; R_0805_2012Metric_Pad1.20x1.40mm_HandSolder
R10: 12k; R_0805_2012Metric_Pad1.20x1.40mm_HandSolder
R20, R21, R27: 470; R_0805_2012Metric_Pad1.20x1.40mm_HandSolder
R22, R23: 5.1k; R_0805_2012Metric_Pad1.20x1.40mm_HandSolder
R28: 1.5k; R_0805_2012Metric_Pad1.20x1.40mm_HandSolder
SW1: EN; SW_SPST_ALPS_SKRKA
SW2: Recal Touch; SW_SPST_ALPS_SKRKA
SW3: Boot; SW_SPST_ALPS_SKRKA
U1: AMS1117-3.3; SOT-223-3_TabPin2
U3: LP2985-3.3; SOT-23-5
U4, U5: ADS1015IDGS; TSSOP-10_3x3mm_P0.5mm
U6: ESP32-WROOM; ESP32-WROOM-32
U7: CH340K; SOP100P600X160-11N
Y1: RV-3028-C7_32.768KHZ_1PPM-TA-QA; RV3028C732768KHZ1PPMTAQA

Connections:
+3.3VP: C1.1, C2.2, C10.1, R7.1, R8.1, R9.1, U3.5, U4.8, U5.8
+3V3: C3.1, C4.1, C7.1, C17.1, C18.1, C19.1, C21.1, C22.1, C27.1, C28.1, C29.1, J6.4, R1.1, R3.1, R4.1, R5.1, R6.1, R10.1, R11.2, R12.1, R18.1, R19.1, R24.1, R25.1, R26.1, R28.1, U1.2, U6.2, U7.7, Y1.7
+5V: C8.1, C15.1, C16.1, C24.1, C25.1, C26.1, D1.1, D4.1, D6.2, F1.2, J7.2, J8.1, U1.3, U3.1, U3.3
/MISO: J8.13, U6.31
/MOSI: J8.6, J8.12, U6.37
/SCK: J8.7, J8.10, U6.30
/TFT_CS: J8.3, U6.23
/TFT_DC: J8.5, U6.26
/TFT_RESET: J8.4, R13.1, U6.24
/Touch_CS: J8.11, R11.1, U6.29
ADC1_0: C5.1, J5.1, R2.2, R28.2
BOOT: Q1.3, R12.2, SW3.1, U6.25
GND: BAT1.1, C1.2, C2.1, C3.2, C4.2, C5.2, C6.2, C7.2, C8.2, C9.2, C10.2, C15.2, C16.2, C17.2, C18.2, C19.2, C20.2, C21.2, C22.2, C23.1, C24.2, C25.2, C26.2, C27.2, C28.2, C29.2, D1.2, D5.1, D6.1, J5.2, J6.6, J6.G1, J6.G2, J6.G3, J6.G4, J7.1, J8.2, J9.2, J10.1, J11.5, J11.6, R13.2, SW1.1, SW2.1, SW3.2, U1.1, U3.2, U4.3, U5.1, U5.3, U6.1, U6.15, U6.38, U6.39, U7.3, U7.11, Y1.5
unnamed: C6.1, R27.2, Y1.6
unnamed: C9.1, U3.4
unnamed: C11.1, J1.5, R16.1, U4.5
unnamed: C11.2, J1.1, R16.2, U4.4
unnamed: C12.1, J2.5, R17.1, U4.7
unnamed: C12.2, J2.1, R17.2, U4.6
unnamed: C13.1, J4.5, R15.1, U5.7
unnamed: C13.2, J4.1, R15.2, U5.6
unnamed: C14.1, J3.5, R14.1, U5.5
unnamed: C14.2, J3.1, R14.2, U5.4
unnamed: C23.2, U7.10
unnamed: D2.1, U4.2
unnamed: D2.2, R8.2
unnamed: D3.1, U5.2
unnamed: D3.2, R9.2
unnamed: D4.2, D5.3, J11.1
unnamed: D5.2, J11.3, U7.1
unnamed: D5.4, J11.2, U7.2
unnamed: F1.1, J9.1, J10.2
unnamed: Q1.1, R22.1
unnamed: Q1.2, R23.2, U7.4
unnamed: Q2.1, R23.1
unnamed: Q2.2, R22.2, U7.6
unnamed: R1.2, SW2.2, U6.5
unnamed: R2.1, U6.4
unnamed: R7.2, U4.1
unnamed: R20.2, U7.8
unnamed: R21.2, U7.9
unnamed: R26.2, Y1.8
RST: C20.1, Q2.3, R10.2, SW1.2, U6.3
RTC_INT: R3.2, U6.7, Y1.2
RXD: R18.2, R20.1, U6.34
SCL_0: R4.2, U6.36, Y1.3
SCL_1: R25.2, U4.10, U5.10, U6.8
SDA_0: R5.2, U6.33, Y1.4
SDA_1: R24.2, U4.9, U5.9, U6.9
SD_CLK: J6.5, U6.13
SD_CS: J6.2, U6.12
SD_DET: J6.CD1, R6.2, U6.6
SD_MISO: J6.7, U6.27
SD_MOSI: J6.3, U6.28
TFT_LED: J8.8, U6.11
TXD: R19.2, R21.1, U6.35
TouchInt: J8.14, U6.10
VBackup: BAT1.2, R27.1

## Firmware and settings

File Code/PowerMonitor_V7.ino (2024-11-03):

#define FILE_NAME "PowerMonitor_V7.ino"

//#define DS3231_RTC
#define RV3028_C7
//#define DELETE_LOG_CONFIG
//#define DELETE_WIFI_CONFIG
//#define FTP_SRVR
//#define SIMPLE_FTP
//#define CT_LEFT_SIDE      // CT-x jacks on left side of case.

//#define REPEAT_TFT_CAL
//#define PRINT_TFT_CAL_DATA
#define TFT_ROTATION 0      // CT jacks: 0 = left side, 2 = right side

#define CORE_0_TASK       // Assigns monitoring of CT inputs to Core 0

//
//  Select SPIFFS_SUPPORT and SD_SUPPORT
//
#define SPIFFS_SUPPORT
#define SD_SUPPORT


#define TFT_320X480           // Portrait 
//#define TFT_480X320           // Landscape

#ifdef TFT_320X480            // Portrait
#define SCREEN_WIDTH 320
#define SCREEN_HEIGHT 480
#elif TFT_480X320             // Landscape
#define SCREEN_WIDTH 480
#define SCREEN_HEIGHT 320
#endif

#define DEFAULT_SSID "ssid"
#define DEFAULT_PASSWORD "password"
#define DEFAULT_FTP_UN "ftp"
#define DEFAULT_FTP_PW "ftp"
#define WIFI_NAME "AmpMeter"

#define RTD_ADC_SAMPLES 5         // Temperature sensor 

#include <Arduino.h>
#include "soc/soc.h"           // Disable brownout problems

#include "soc/rtc_cntl_reg.h"  // Disable brownout problems
#include <TimeLib.h>

#include <Adafruit_ADS1X15.h>
Adafruit_ADS1015 ads48;  
Adafruit_ADS1015 ads49;      

#ifdef CORE_0_TASK
TaskHandle_t Task1;
#endif

//
//  Project Files
//
#include "xSPIFFS.h"
#include "xWiFi.h"
#include "Meter.h"
#include "TFT.h"
#include "RTC_NTP.h"
#include "xTimeZone.h"
#include "xKeyboard.h"
#include "Buttons.h"
#include "Log.h"


//
//  Included Library
//
#ifdef FTP_SRVR
#include <ESP8266FtpServer.h>
#endif
#ifdef SIMPLE_FTP
#include <SimpleFTPServer.h>
#endif
#include "WiFi.h"
#include <WiFiUdp.h>
#include <NTPClient.h>

#include "TFT_eSPI.h"

#include "Free_Fonts.h"

#ifdef SD_SUPPORT
#include "SD.h"
#endif

#define PAD 0
//
//  SPIFFS files
//   File names (fn.....)
//
#define CHAN_1_CONFIG_FN "/Chan1config.bin"
#define CHAN_2_CONFIG_FN "/Chan2config.bin"
#define CHAN_3_CONFIG_FN "/Chan3config.bin"
#define CHAN_4_CONFIG_FN "/Chan4config.bin"

const char* fnTftCal = "/tftcal.bin";
const char* fnWifiConfig = "/wifi.bin";
const char* fnTimeZoneConfig = "/timezone.bin";
const char* fnLogConfig = "/LogConfig.bin";
const char* fnEventLog = "/EventLog.csv";
const char* fnIntervalLog = "/IntervalLog.csv";
char fnInterval[16];
char fnEvent[16];

//
//
//
int ssidSelectIndex = 0;
bool ssidSelected = false;
//  WiFi SSID and Password
char tempSSID[32];
char tempPW[32];
bool changedSSID = false;
bool changedWiFiPW = false;
bool changedWiFiEnable = false;
//  FTP Username and Password
char tempFtpUN[32];
char tempFtpPW[32];
bool changedFtpUN = false;
bool changedFtpPW = false;
bool changedFtpEnable = false;

bool changedLogConfig = false;

//
//  NTP - Network Time Protocol
//
const char* ntpServer1 = "time.nist.gov";
const char* ntpServer2 = "ptbtime1.ptb.de";
const char* ntpServer3 = "pool.ntp.org";

WiFiUDP ntpUDP;
NTPClient timeClient(ntpUDP, "us.pool.ntp.org", 0);   //-7*3600);

#ifdef FTP_SRVR
FtpServer ftpSrv;
#endif
#ifdef SIMPLE_FTP
FtpServer ftpSrv;
#endif
TFT_eSPI myTFT = TFT_eSPI();       // Invoke custom library

const GFXfont *gfxFont = NULL;



///////////////////////////////////////
//
//  ESP32 Pin Definitions
//
#define REPEAT_CAL_PIN  39    // (39 = VN)

// ----- TFT -----             Net Name
//#define TFT_DIN 23          // MOSI & Touch_DIN
//#define TFT_SCK 18          // SCK (both TFT and Touch)
#define TFT_LED   26          // TFT_LED, control pin
#define TFT_CS    15          // TFT_CS
#define TFT_RESET 2           // TFT_RESET
#define TFT_DC    4           // TFT_DC
//#define TOUCH_INT_PIN 25    // TouchInt
//#define TOUCH_DOUT  19      // Touch_DOUT & MISO
#define TOUCH_CS_PIN    5     // Touch_CS

// ----- ADC -----
#define ADC1_0  36      // (36=VP) Temperature Sensor

// ------ RTC -----
#define RTC_INT_PIN   35      // RTC_INT

//
// Wire definitions
//
#define SDA_0 21    // SDA_0
#define SCL_0 22    // SCL_0

#define SDA_1 33    // SDA_1
#define SCL_1 32    // SCL_1

TwoWire I2C_0 = TwoWire(0);     // RTC
TwoWire I2C_1 = TwoWire(1);     // ADC's

//
// ----- SD Card -----
//
//#ifdef SD_SUPPORT
// Pin Definitions          Net Name
#define HSPI_MISO   16    // SD_MISO
#define HSPI_MOSI   17    // SD_MOSI
#define HSPI_SCLK   14    // SD_CLK
#define HSPI_SS     27    // SD_CS
#define SD_CARD_DET 34    // SD_DET

#define SD_SPI_FREQ 1000000
SPIClass hspi = SPIClass(HSPI);
//#endif

//
//  Temperature Sensor
//
#define Rref 1500     //1800

#define nominal_resistance 1093       //Nominal resistance at 25⁰C
#define nominal_temperature 25   // temperature for nominal resistance (almost always 25⁰ C)
#define beta -375   //3950  // PTC, The beta coefficient or the B value of the thermistor check the datasheet for the accurate value.


#define LINE_VOLTAGE  120.0     //230.0
#define LINE_FREQ 60.0          //50.0

//
//  NUMBER_SAMPLES multipled by sample time should be a multiple of line period (frequency).
//  Line period = 16.666ms
//
#define NUMBER_SAMPLES 10 
//#define DEBUG_SAMPLE_COUNT

#define LOOP_TIME 166        // 166 milliseconds

float multiplier = 0.001;   // 1 mV

struct CHAN_CONFIG_STRUCT {
  int index;
  boolean enabled;
  float range;             // 5, 10, 15, 20 Amp max
  int lineV;
}; 

CHAN_CONFIG_STRUCT CT1 = { 0, true, 50.0, 120};            // CT1, CT2, CT3, CT4
CHAN_CONFIG_STRUCT CT2 = { 1, true, 50.0, 120};
CHAN_CONFIG_STRUCT CT3 = { 2, true, 30.0, 120};
CHAN_CONFIG_STRUCT CT4 = { 3, true, 30.0, 120};

CHAN_CONFIG_STRUCT prevChanConfig;

String chanConfigFN[4] = {CHAN_1_CONFIG_FN, CHAN_2_CONFIG_FN, CHAN_3_CONFIG_FN, CHAN_4_CONFIG_FN};

struct CHAN_DATA_STRUCT {
  int number;
  float Irms;
  float prevIrms;
  float watts;        
  float fullScale;
  int v100;
  int v10;
  int v1;
  bool changed;
  bool load;        // true if Irms > 0.100 else false
  bool prevLoad;
}; 

CHAN_DATA_STRUCT chanData1 = {1, 0.0, 5.0, 0.0,
      8.0, 0, 0, 0, false, false, false
      };
CHAN_DATA_STRUCT chanData2 = {2, 0.0, 5.0, 0.0,
      16.0, 0, 0, 0, false, false, false
      };
CHAN_DATA_STRUCT chanData3 = {3, 0.0, 5.0, 0.0,
      16.0, 0, 0, 0, false, false, false
      };
CHAN_DATA_STRUCT chanData4 = {4, 0.0, 5.0, 0.0,
      24.0, 0, 0, 0, false, false, false
      };

//
//  TFT Brightness Control pins
//
// SPI TFT ONLY !!!
#define LED_PWM_CHANNEL    0
#define LED_PWM_FREQ       1000      // 5000Hz
#define LED_PWM_RESOLUTION 8         // 8 bits
#define TFT_LED_TIMEOUT 180

#include <driver/adc.h>

////////////////////////////////////////
//
//  Definitions
//
enum MENU_STATE { MAIN_MENU, CHAN_1_MENU, CHAN_2_MENU, CHAN_3_MENU, 
                  CHAN_4_MENU, CHAN_CONFIG_MENU, VOLTAGE_KPAD, SYSTEM_MENU,
                  KEYBOARD_MENU, TZ_MENU, REGION_MENU, CITY_MENU,
                  WIFI_MENU, SSID_MENU, FTP_MENU, LOG_MENU, ELOG_MENU,
                  ILOG_MENU, ILOG_KPAD, ELOG_KPAD, ELOG_CT_MENU,
                  SD_MENU, ABOUT_MENU };


enum TFT_LED_STATE {TFT_LED_OFF, TFT_LED_ON, TFT_LED_FADE_UP, TFT_LED_FADE_DOWN};

///////////////////////////////////////
//
//  Global Varibles
//
//
//   ----- boolean -----
bool interruptTriggered = false;
bool WiFi_Connect_Flag = false;
bool FanOn = false;
bool AugerOn = false;
bool HeaterOn = false;
bool epochTimeValid = false;
bool ftpTIP = false;          // ftp Transfer In Progress
bool SD_CardPresent = false;
//   ----- int -----
int menuState = MAIN_MENU;
int logIntervalTimer = 0;
int ledTimer = TFT_LED_TIMEOUT;
int prevTempF = 70;
int temperatureF;
int temperatureC;
int dutyCycle = 255;    // TFT LED dutycycle  (255 = FULL ON, 0 = OFF)
int fileCnt = 0;
int dirCnt = 0;
int tmpIntValue = 0;
int tmpEventValue = 5;      // actually 0.5
int eLogCTn = 1;            // only 1, 2, 3 or 4
int tmpLineV = 0;
static int currentDay = 32;
int readChan = 1;
int tftLedState = TFT_LED_ON;
//int gblV100 = 0;
//int gblV10 = 0;
//int gblV1 = 0;
//   ----- long -----
unsigned long time_now = 0;
unsigned long timePeriodStart = 0;
unsigned long ckTperiod = 2000;     // 2 seconds
unsigned long epochTime = 0;
//   ----- double -----

//   ----- float -----
float IrmsC1 = 0;
float prevIrmsC1 = 0;
float IrmsC2 = 0;
float prevIrmsC2 = 0;
float IrmsC3 = 0;
float prevIrmsC3 = 0;
float IrmsC4 = 0;
float prevIrmsC4 = 0;

// Arrays
char chrBuf[64];
char timeTxt[16];
char ideVer[64];
char logText[64];
String ipAddr;
String macAddr;
int chanPage[5] = { 0, CHAN_1_MENU, CHAN_2_MENU, CHAN_3_MENU, CHAN_4_MENU};

CHAN_CONFIG_STRUCT *pChanConfig = &CT1;
CHAN_DATA_STRUCT *pChanData = &chanData1;

struct SD_CARD_STRUCT {
  bool present;
  bool mounted;
  int Type;         // Card type
  char cType[16];
  uint64_t Size;       // Card size
  float SizeGB;
  uint64_t Capacity;   // Total bytes
  uint64_t Available;    // Used bytes
  uint64_t Used;    // Used bytes
} sdCard;

//
//  Clock Variables
//
char TOD[8];
int isdst = 0;
int offsetTZ;
byte clockhour; // Holds current hour value
byte clockminute; // Holds current minute value
byte clocksecond;
bool waiting4ZeroSecond = true;
struct tm *timeinfo;


//
//  Keypad Small global variables
//
int kpsValue = 0;
int *pDelay;
boolean beforeSun;
boolean changedMins = false;

//
//  Keyboard variables
//
#define INPUT_STR_SZ 24
int kbMaxCharCnt = INPUT_STR_SZ;
void (*fpKeyboardPP)() = NULL;
void (*fpTimeConfigPP)() = NULL;
int kbStringIndex = 0;
char kbString[INPUT_STR_SZ + 2];
char kbTitle[40];
#define NAME_MAX_LEN 14

///////////////////////////////////////////////////////////
//
//
//
//
void setup()
{
  WRITE_PERI_REG(RTC_CNTL_BROWN_OUT_REG, 0); //disable brownout detector  
  pinMode(REPEAT_CAL_PIN, INPUT);

  Serial.begin(115200);
  Serial.println("");
  Serial.println(FILE_NAME);
  // Combined string in RAM
  //Serial.println( "Compiled: " __DATE__ ", " __TIME__ ", " __VERSION__);
  Serial.print( F("Compiled: "));
  Serial.print( F(__DATE__));
  Serial.print( F(", "));
  Serial.print( F(__TIME__));
  Serial.print( F(", "));
  Serial.println( F(__VERSION__));

  sprintf(ideVer, "IDE Version: %d.%d.%d", ARDUINO / 10000, (ARDUINO / 100) % 100, ARDUINO % 100); 
  Serial.print(F( "Arduino IDE version: "));
  Serial.print(ARDUINO / 10000, DEC);
  Serial.print(".");
  Serial.print((ARDUINO / 100) % 100, DEC);
  Serial.print(".");
  Serial.println(ARDUINO % 100, DEC);
  //
  //  Setup TFT
  //
  myTFT.begin();
  myTFT.setRotation(TFT_ROTATION); // 0 or 2 - Inverted to accomodate USB cable
  
  if (digitalRead(REPEAT_CAL_PIN) == 0)
  {
    Serial.println("Repeat TFT Calibration");
    calibrateTftTouch = true;
  }
  //
  //
  // Set I2c bus to 400kHz, default is 100kHz
  //
  //
  I2C_0.begin(SDA_0, SCL_0, 100000);    // RTC
  I2C_1.begin(SDA_1, SCL_1, 400000);    // ADCs
  //Wire.begin();
  //Wire.setClock(400000);
  Serial.println(I2C_0.getClock());
  Serial.println(I2C_1.getClock());
  
  initSPIFFS();           // Initialize SPIFFS file system

  pinMode(SD_CARD_DET, INPUT);
  delay(100);
  Serial.println(digitalRead(SD_CARD_DET));
  if(digitalRead(SD_CARD_DET) == 1) Serial.println("SD Card Missing");
  else Serial.println("SD CARD Present");
  
  //
  // Setup TFT LED
  //
  pinMode(TFT_LED, OUTPUT);
  digitalWrite(TFT_LED, HIGH);
  
  touch_calibrate();

  myTFT.fillScreen(TFT_BLACK);
  //  myTFT.setSwapBytes(true);
  setGfxFont(NULL);
  myTFT.setTextSize(3);        // Text size multiplier = 3X
  myTFT.setTextColor(TFT_GREEN, TFT_BLACK);
  myTFT.setTextDatum(TC_DATUM);         // Center Text

  //
  //  Load Logging configuration
  //
  loadLogConfig();
  
  //
  // Load WiFi configuration
  //
  loadWiFiConfig();
  if(WiFiConfig.enabled)
  {
    // Initialize WiFi connection
    myTFT.drawString("Connecting", 160, 90);
    myTFT.drawString("to WiFi", 160, 120);
    if (initWiFi())
    {
      WiFi_Connect_Flag = true;
      Serial.println("WiFi Connected");
      myTFT.fillScreen(TFT_BLACK);
      myTFT.drawString("WiFi Connected", 160, 100);
      myTFT.drawString(WiFi.localIP().toString(),160, 140);
      delay(2000);
    }
    else
    {
      WiFi_Connect_Flag = false;
      Serial.println("WiFi Failed");
      myTFT.fillScreen(TFT_BLACK);
      myTFT.drawString("WiFi Failed", 160, 90);
      myTFT.drawString("to Connect", 160, 120);
      delay(2000);
    }
  }
  else    // Turn WiFi OFF
  {
    WiFi.mode(WIFI_OFF);
    btStop();
  } 
  
#ifdef FTP_SRVR
  if(WiFi_Connect_Flag && WiFiConfig.ftpEnabled)
  {
    Serial.println("Starting FTP Server");
    ftpSrv.begin(WiFiConfig.ftpUserName, WiFiConfig.ftpPassWord);
    Serial.printf("un: %s    pw: %s\n\r",WiFiConfig.ftpUserName, WiFiConfig.ftpPassWord);
  }
#endif


  myTFT.setTextDatum(TC_DATUM);         // Center Justify Text
  myTFT.fillScreen(TFT_BLACK);          // erase screen

  //
  // Initialize the Real Time Clock chip
  //
  if (RTC_init())
  {
    myTFT.drawString("RTC Connected", 160, 100);
    Serial.println("RTC Connected");
    delay(1000);
    if(WiFi_Connect_Flag)
    {
      
    }
  }
  else
  {
    myTFT.drawString("RTC Failed", 160, 90);
    myTFT.drawString("to Connect", 160, 120);
    delay(2000);
  }

#ifdef SD_SUPPORT
  init_SD();
#endif

#ifdef SIMPLE_FTP
  if(WiFi_Connect_Flag && WiFiConfig.ftpEnabled)
  {
    ftpSrv.setCallback(_callback);
    ftpSrv.setTransferCallback(_transferCallback);
    Serial.println("Starting Simple FTP Server");
    ftpSrv.begin(WiFiConfig.ftpUserName, WiFiConfig.ftpPassWord);
    Serial.printf("un: %s    pw: %s\n\r",WiFiConfig.ftpUserName, WiFiConfig.ftpPassWord);
  }
#endif

  //delay(60000);
  //  delay(10000)
  setGfxFont(FSS9);
  myTFT.setTextDatum(TL_DATUM);         // Left Justify Text
  myTFT.fillScreen(TFT_BLACK);          // erase screen
  //myTFT.setTextFont(4);
  myTFT.setTextSize(1);
  myTFT.setTextColor(TFT_WHITE, TFT_BLACK);
  
  // configure the Time Zone
  configTZ();

  //Serial.print("Vcc = ");
  //Serial.println(emon1.readVcc()); 

  /* Get our time sync started */
  /* Set our position and a default timezone value */
  calcTZoffset();   // DST offset
  Serial.printf("DST offsetTZ = %d\n\r", offsetTZ);
  
  //
  //  Setup Time sync provider (NTP or RTC)
  //
  if(WiFiConfig.enabled && WiFi_Connect_Flag) 
  {
    setTime((time_t)getNtpTime());
    setSyncProvider(getNtpTime);
    setSyncInterval(60*60);       // 3600 seconds (1 hour)
  }
  else
  {
    setSyncProvider(time_provider);
    setSyncInterval(60*60);       // 3600 seconds (1 hour)
  }    

  //
  //  Initialize ADS1015 ADC's
  //
  Serial.println("Initialize ADC's");
  initChannels();
  initADS48();
  initADS49();  

  #ifdef CORE_0_TASK
  //create a task that will be executed in the readADC_Task() function, with priority 1 and executed on core 0
  xTaskCreatePinnedToCore(
                    readADC_Task,   /* Task function. */
                    "ADC_Task",     /* name of task. */
                    10000,       /* Stack size of task */
                    NULL,        /* parameter of the task */
                    1,           /* priority of the task */
                    &Task1,      /* Task handle to keep track of created task */
                    0);          /* pin task to core 0 */                  
  delay(500); 
#endif

  //
  //  Display Initial Screen
  //
  drawMainMenu();

}


///////////////////////////////////////////////////////////
//
//    Main LOOP
//
//
 int tstv = 0;
 //
void loop()
{
#ifdef DS3231_RTC
    //
    //  RTC alarm #2 interrupt (occurs every minute)
    //
    if (rtc.alarmFired(ALARM_2))  // clear RTC alarm #2 interrupt (occurs once a minute)
    {
      rtc.clearAlarm(ALARM_2);
      printLocalTime(); // Recalculate current time
    }
    //
    //  RTC alarm #1 interrupt (occurs every second)
    //
    if (rtc.alarmFired(ALARM_1))  // clear RTC alarm #1 interrupt (occurs every second)
    {
      rtc.clearAlarm(ALARM_1);
      logging();
     if(ledTimer) 
     {
       ledTimer--;
     }
     else digitalWrite(TFT_LED, LOW);
#ifdef TEMPERATURE_ENABLED
    checkTemp();
    if(temperatureF != prevTempF)
    {
      //myTFT.setCursor(5, pgLine12);   // x,y pixels
      clearLine(pgLine12);
      //myTFT.setCursor(5, pgLine12);
      //myTFT.print("Temperature = ");
      //myTFT.print(temperatureF);
      //myTFT.print("\x60""F  ");
      sprintf(chrBuf,"Temperature = %3d\x60""F  ",temperatureF);
      myTFT.drawString(chrBuf, 5, pgLine12);
      prevTempF = temperatureF;
    }
#endif

#ifdef DEBUG_SAMPLE_COUNT
    unsigned long timethen = millis();
    Irms = emon1.calcIrms(1978);
    unsigned long timenow = millis();
    Serial.print("Time ");
    Serial.println(timenow - timethen);
#endif
  }       // end of if(ALARM_1)
#endif    // DS3231_RTC

#ifdef RV3028_C7
  if (interruptTriggered) 
  {
    interruptTriggered = false;
    //
    // The following is required to get the time 
    //  display to update exactly on the minute.
    //  This code is only executed once
    //  at power-on or reset.
    //
    if(waiting4ZeroSecond)
    {
      time_t rawTime = rtc.getUnixTimestamp();
      timeinfo = localtime(&rawTime);
      if(timeinfo->tm_sec == 0)
      {
        waiting4ZeroSecond = false;
        rtc.startPeriodicCountdownTimer();    // Minutes
      }
    }
    //
    // This interrupt occurs once a Minute
    //
    if (rtc.isInterruptDetected(INTERRUPT_PERIODIC_COUNTDOWN_TIMER)) 
    {
      rtc.clearInterrupt(INTERRUPT_PERIODIC_COUNTDOWN_TIMER);
      printLocalTime(); // Recalculate current time
      if(menuState == MAIN_MENU)
      {
        displayTOD();
        displayLogStatus();
      }
    }   // end of One Minute interrupt processing
    //
    // This interrupt occurs every Second
    //
    if (rtc.isInterruptDetected(INTERRPUT_PERIODIC_TIME_UPDATE)) 
    {
      rtc.clearInterrupt(INTERRPUT_PERIODIC_TIME_UPDATE);
      logging();
      if(ledTimer)
      {
        ledTimer--;
      }
      else digitalWrite(TFT_LED, LOW);
#ifdef TEMPERATURE_ENABLED
      checkTemp();
      if(temperatureF != prevTempF)
      {
        //myTFT.setCursor(5, pgLine12);   // x,y pixels
        clearLine(pgLine12);
        //myTFT.setCursor(5, pgLine12);
        //myTFT.print("Temperature = ");
        //myTFT.print(temperatureF);
        //myTFT.print("\x60""F  ");
        sprintf(chrBuf,"Temperature = %3d\x60""F  ",temperatureF);
        myTFT.drawString(chrBuf, 5, pgLine12);
        prevTempF = temperatureF;
      }
#endif

#ifdef DEBUG_SAMPLE_COUNT
      unsigned long timethen = millis();
      Irms = emon1.calcIrms(1978);
      unsigned long timenow = millis();
      Serial.print("Time ");
      Serial.println(timenow - timethen);
#endif
    }    
    rtc.clearAllInterrupts();
  }   // end of RV3028_C7 RTC Interrupt processing
#endif

  //
  //
  //
  if(ftpTIP == false)
  {
    switch(menuState)
    {
      case MAIN_MENU:
      case CHAN_1_MENU:
      case CHAN_2_MENU:
      case CHAN_3_MENU:
      case CHAN_4_MENU:
        readNextChannel();
        break;
      default:
        break;
    }
  }
  //
  //
  //
  if(touchCheck())
  {
    digitalWrite(TFT_LED, HIGH);
    ledTimer = TFT_LED_TIMEOUT;
    processTouch(btnDecode(4,6));
    //Serial.printf("touch button %d\n\r",touchData.button);
  }
  //
  //    Display Main Menu or Channel Menu.
  //
  menuProcessor();

#ifdef FTP_SRVR
  if(WiFi_Connect_Flag)
  {
    //Serial.println("handleFTP");
    ftpSrv.handleFTP();
  }
#endif
#ifdef SIMPLE_FTP
  if(WiFi_Connect_Flag)
  {
    //Serial.println("handle_Simple_FTP");
    ftpSrv.handleFTP();
  }
#endif
}       // end of loop()

//////////////////////////////////////////////////////
//
//
//
void readNextChannel(void)
{
#ifndef CORE_0_TASK
  //
  //  Read Channel ADC
  //
  //    read one channel per Loop
  //
  switch(readChan)
  {
    case 1:
      chanData1.Irms = chan1readACcurrent();
      if(chanData1.Irms < 0.050) chanData1.Irms = 0.0;
      chanData1.watts = chanData1.Irms * (float)(CT1.lineV);
      if(abs(chanData1.prevIrms - chanData1.Irms) >= 0.050) chanData1.changed = true;
      // Logging
      if(chanData1.Irms >= 0.050) chanData1.load = true;
      else chanData1.load = false;
      //
      readChan = 2;
      break;
    case 2:
      chanData2.Irms = chan2readACcurrent();
      if(chanData2.Irms < 0.050) chanData2.Irms = 0.0;
      chanData2.watts = chanData2.Irms * (float)(CT2.lineV);
      if(abs(chanData2.prevIrms - chanData2.Irms) >= 0.050) chanData2.changed = true;
      if(chanData2.Irms >= 0.050) chanData2.load = true;
      else chanData2.load = false;
      readChan = 3;
      break;
    case 3:
      chanData3.Irms = chan3readACcurrent();
      if(chanData3.Irms < 0.050) chanData3.Irms = 0.0;
      chanData3.watts = chanData3.Irms * (float)(CT3.lineV);
      if(abs(chanData3.prevIrms - chanData3.Irms) >= 0.050) chanData3.changed = true;
      if(chanData3.Irms >= 0.050) chanData3.load = true;
      else chanData3.load = false;
      readChan = 4;
      break;
    case 4:
      chanData4.Irms = chan4readACcurrent();
      if(chanData4.Irms < 0.050) chanData4.Irms = 0.0;
      chanData4.watts = chanData4.Irms * (float)(CT4.lineV);
      if(abs(chanData4.prevIrms - chanData4.Irms) >= 0.050) chanData4.changed = true;
      if(chanData4.Irms >= 0.050) chanData4.load = true;
      else chanData4.load = false;
      readChan = 1;
      break;
  }
#endif
}

////////////////////////////////////////////////////////////
//
//  Print Local Time
//
void printLocalTime()
{
  Update_timeinfo();
  clockhour = timeinfo->tm_hour;
  clockminute = timeinfo->tm_min;
  clocksecond = timeinfo->tm_sec;
  Serial.println(timeinfo, "%A, %B %d %Y %H:%M:%S");
}
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

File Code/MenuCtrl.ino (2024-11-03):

//////////////////////////////////////////////////////
//
//
#define MENU_STACK_SIZE 16
int menuStack[MENU_STACK_SIZE];
int menuStkPtr = 0;
//
//
//
//void emptyMenuStack(void)
//{
//  menuStkPtr = 0;
//}

////////////////////////////////////////
//
//  pushMenu
//
void pushMenu(int newMenu)
{
  if (menuStkPtr < MENU_STACK_SIZE)
  {
#ifdef PUSH_POP_DEBUG
    Serial.print(menuStkPtr);
    Serial.print("  PUSH  ");
    Serial.println(menu);
#endif
    menuStack[menuStkPtr++] = menuState;
    menuState = newMenu;
    drawMenu(menuState);
  }
  else
  {
    Serial.println("Menu stack overflow");
    //sysLog("Menu stack overflow");
    // Dump Stack
    for (int i = 0; i < MENU_STACK_SIZE; i++)
    {
      Serial.printf("%d = %d\r\n", i, menuStack[i]);
    }
    delay(2000);
    ESP.restart();
    while (1);
  }
}

////////////////////////////////////
//
//  popMenu
//
void popMenu(void)
{
  if (menuStkPtr > 0)
  {
#ifdef PUSH_POP_DEBUG
    Serial.print(menuStkPtr);
#endif
    --menuStkPtr;
#ifdef PUSH_POP_DEBUG
    Serial.print("  POP  ");
    Serial.println(menuStack[menuStkPtr]);
#endif
    menuState = menuStack[menuStkPtr];
    drawMenu(menuState);
  }
  else
  {
    Serial.println("Menu stack underflow");
    //sysLog("Menu stack underflow");
    // Dump Stack
    for (int i = 0; i < MENU_STACK_SIZE; i++)
    {
      Serial.printf("%d = %d\r\n", i, menuStack[i]);
    }
    delay(2000);
    ESP.restart();
    while (1);
  }
}

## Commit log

2024-11-04 Update with images
    [AmpMtrXSmallBack_V4.FCStd, AmpMtrXSmallBack_V4.stl, NewAmpMeter_V4_Cpy11.FCStd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]
2024-11-05 ReadMe update
    [PowerMonitor_V6.csv, PowerMonitor_V7_2.csv, PowerMonitor_V7_2.kicad_pcb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]
